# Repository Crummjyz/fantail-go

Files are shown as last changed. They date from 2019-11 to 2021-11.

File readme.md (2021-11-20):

# Fantail Go
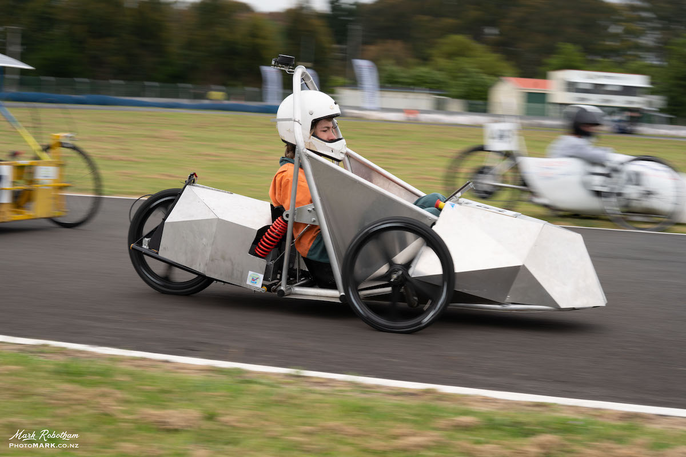
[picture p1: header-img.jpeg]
A go-kart in motion

Throughout 2019, we, a group of students, worked to build an electric go-kart from the ground up. Across the entire vehicle _everything_ was controlled digitally via a pair of Raspberry Pi’s — giving us detailed control over performance, and _lots_ of diagnostics data.

**This repository is not a prepared do-it-yourself project.** Instead, we hope that it might provide some appreciated insight into someone else’s approaches to common problems, for your own work.

The structural and mechanical designs will remain private.

## Repository Structure
#### [vehicle](https://github.com/Crummjyz/fantail-go/tree/main/vehicle)
The code running on each of the onboard Raspberry Pi’s, providing control of the vehicle and data transmission/processing.
_Note — the programs in the ‘tests’ folders are not software tests, but small, isolated scripts to allow manual operation of some hardware components. _

#### [dash](https://github.com/Crummjyz/fantail-go/tree/main/dash)
A Flutter app to display realtime data to the driver.

#### [board](https://github.com/Crummjyz/fantail-go/tree/main/board)
The EAGLE files for our custom PCB/breakout-board.

---- 
_This repository was originally at [https://github.com/Fantail-Dev/fantail-go](https://github.com/Fantail-Dev/fantail-go). It has been migrated here for easier oversight._

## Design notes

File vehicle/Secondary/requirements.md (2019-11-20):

# Requirements (Main Raspberry Pi)
## Tasks
- Send log data to phone for transmission
- Recieve log data from Drive Pi
- Send info data to display
- Read temperatures from sensors
- Read accelerometer data
- Send configuration commands to Drive Pi
- Recieve configuration commands from phone
- Send bluetooth connection setup to tablet or phone
- Read battery voltage
- Read current draw/charge rate

## Connections
| Device | Method
| --- | ---
| Drive Pi | Ethernet
| Phone | USB UART/Bluetooth
| Temperature Sensors/ADC | I<sup>2</sup>C
| Display | USB UART/Bluetooth
| Accelerometer | I<sup>2</sup>C
| Battery Voltage/ADC | I<sup>2</sup>C
| Battery Current/ADC | I<sup>2</sup>C

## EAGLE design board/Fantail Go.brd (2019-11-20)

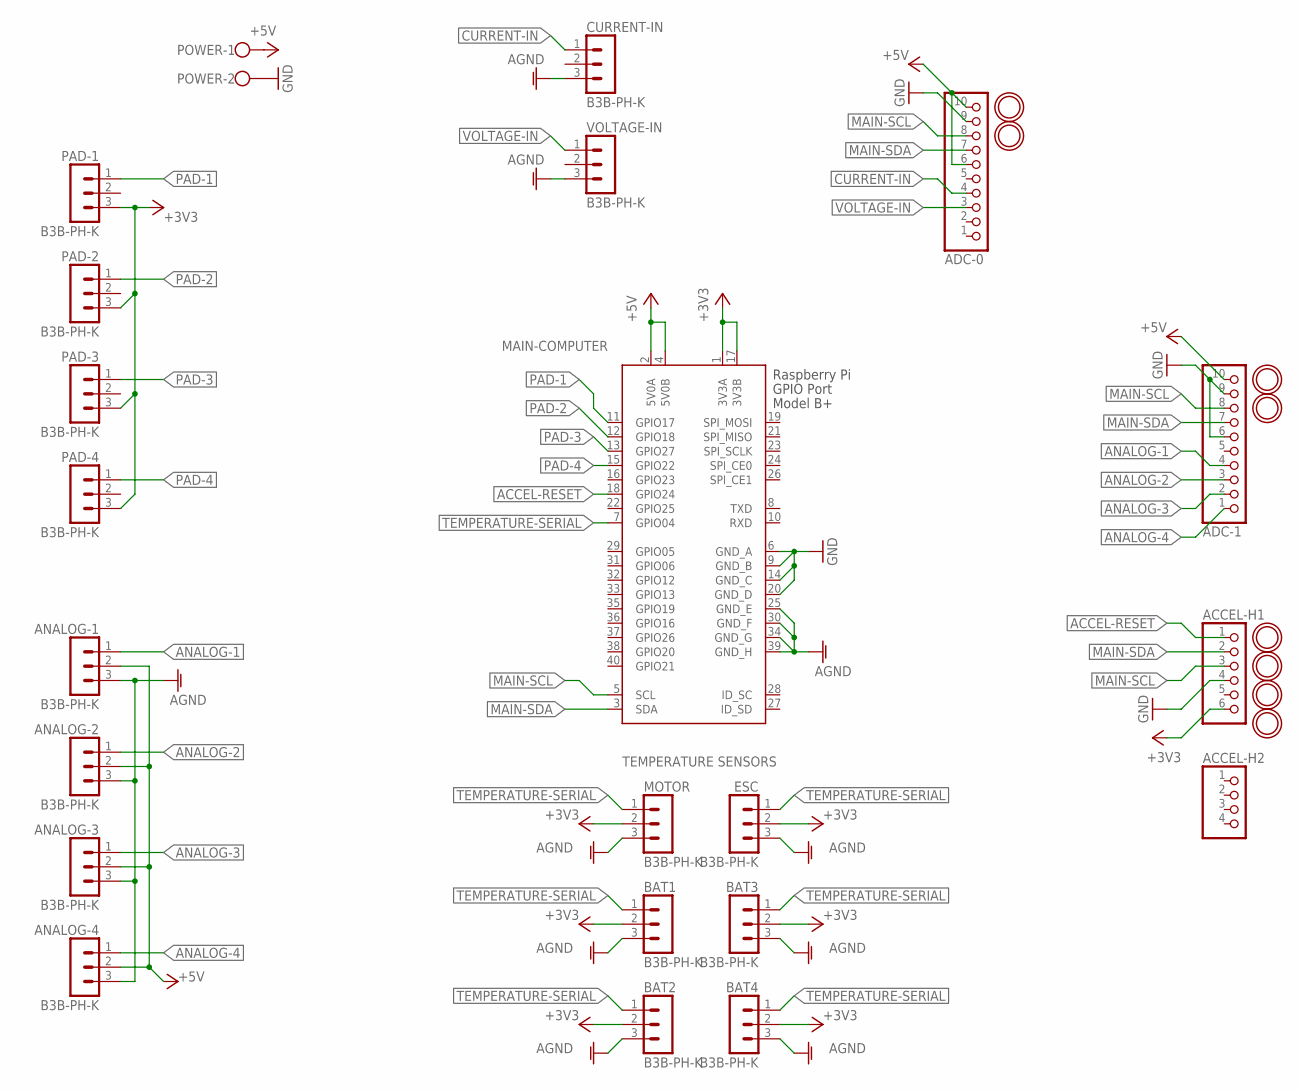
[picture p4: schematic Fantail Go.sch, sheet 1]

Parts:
ACCEL-H1: HEADER-1X670MIL; 1X06_ROUND_70
ACCEL-H2: HEADER-1X4ROUND; 1X04_ROUND
ADC-0, ADC-1: HEADER-1X1070MIL; 1X10_ROUND70
ANALOG-1, ANALOG-2, ANALOG-3, ANALOG-4: B3B-PH-K
BAT1, BAT2, BAT3, BAT4: B3B-PH-K
CURRENT-IN: B3B-PH-K
ESC: B3B-PH-K
MOTOR: B3B-PH-K
PAD-1, PAD-2, PAD-3, PAD-4: B3B-PH-K
POWER: W237-102
U$5, U$15, U$16, U$18, U$19, U$20, U$21, U$22: MOUNTINGHOLE2.5; MOUNTINGHOLE_2.5_PLATED
VOLTAGE-IN: B3B-PH-K
X1: RASPI_BOARD_B+#_F; RASPI_BOARD_B+_FULL

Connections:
+3V3: ACCEL-H1.6, BAT1.2, BAT2.2, BAT3.2, BAT4.2, ESC.2, MOTOR.2, PAD-1.3, PAD-2.3, PAD-3.3, PAD-4.3, X1.1 (3V3A), X1.17 (3V3B)
+5V: ADC-0.6, ADC-0.10, ADC-1.10, ANALOG-1.2, ANALOG-2.2, ANALOG-3.2, ANALOG-4.2, POWER.1, X1.2 (5V0A), X1.4 (5V0B); also elsewhere on the board
ACCEL-RESET: ACCEL-H1.1, X1.18 (GPIO24)
AGND: ANALOG-1.3, ANALOG-2.3, ANALOG-3.3, ANALOG-4.3, BAT1.3, BAT2.3, BAT3.3, BAT4.3, CURRENT-IN.3, ESC.3, MOTOR.3, VOLTAGE-IN.3, X1.25 (GND_E), X1.30 (GND_F), X1.34 (GND_G), X1.39 (GND_H)
ANALOG-1: ADC-1.4, ANALOG-1.1
ANALOG-2: ADC-1.3, ANALOG-2.1
ANALOG-3: ADC-1.2, ANALOG-3.1
ANALOG-4: ADC-1.1, ANALOG-4.1
CURRENT-IN: ADC-0.4, CURRENT-IN.1
GND: ACCEL-H1.4, ADC-0.9, ADC-1.6, ADC-1.9, POWER.2, X1.6 (GND_A), X1.9 (GND_B), X1.14 (GND_C), X1.20 (GND_D); also elsewhere on the board
MAIN-SCL: ACCEL-H1.3, ADC-0.8, ADC-1.8, X1.5 (SCL)
MAIN-SDA: ACCEL-H1.2, ADC-0.7, ADC-1.7, X1.3 (SDA)
PAD-1: PAD-1.1, X1.11 (GPIO17)
PAD-2: PAD-2.1, X1.12 (GPIO18)
PAD-3: PAD-3.1, X1.13 (GPIO27)
PAD-4: PAD-4.1, X1.15 (GPIO22)
TEMPERATURE-SERIAL: BAT1.1, BAT2.1, BAT3.1, BAT4.1, ESC.1, MOTOR.1, X1.7 (GPIO04)
VOLTAGE-IN: ADC-0.3, VOLTAGE-IN.1

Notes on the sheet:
TEMPERATURE SENSORS
MAIN-COMPUTER

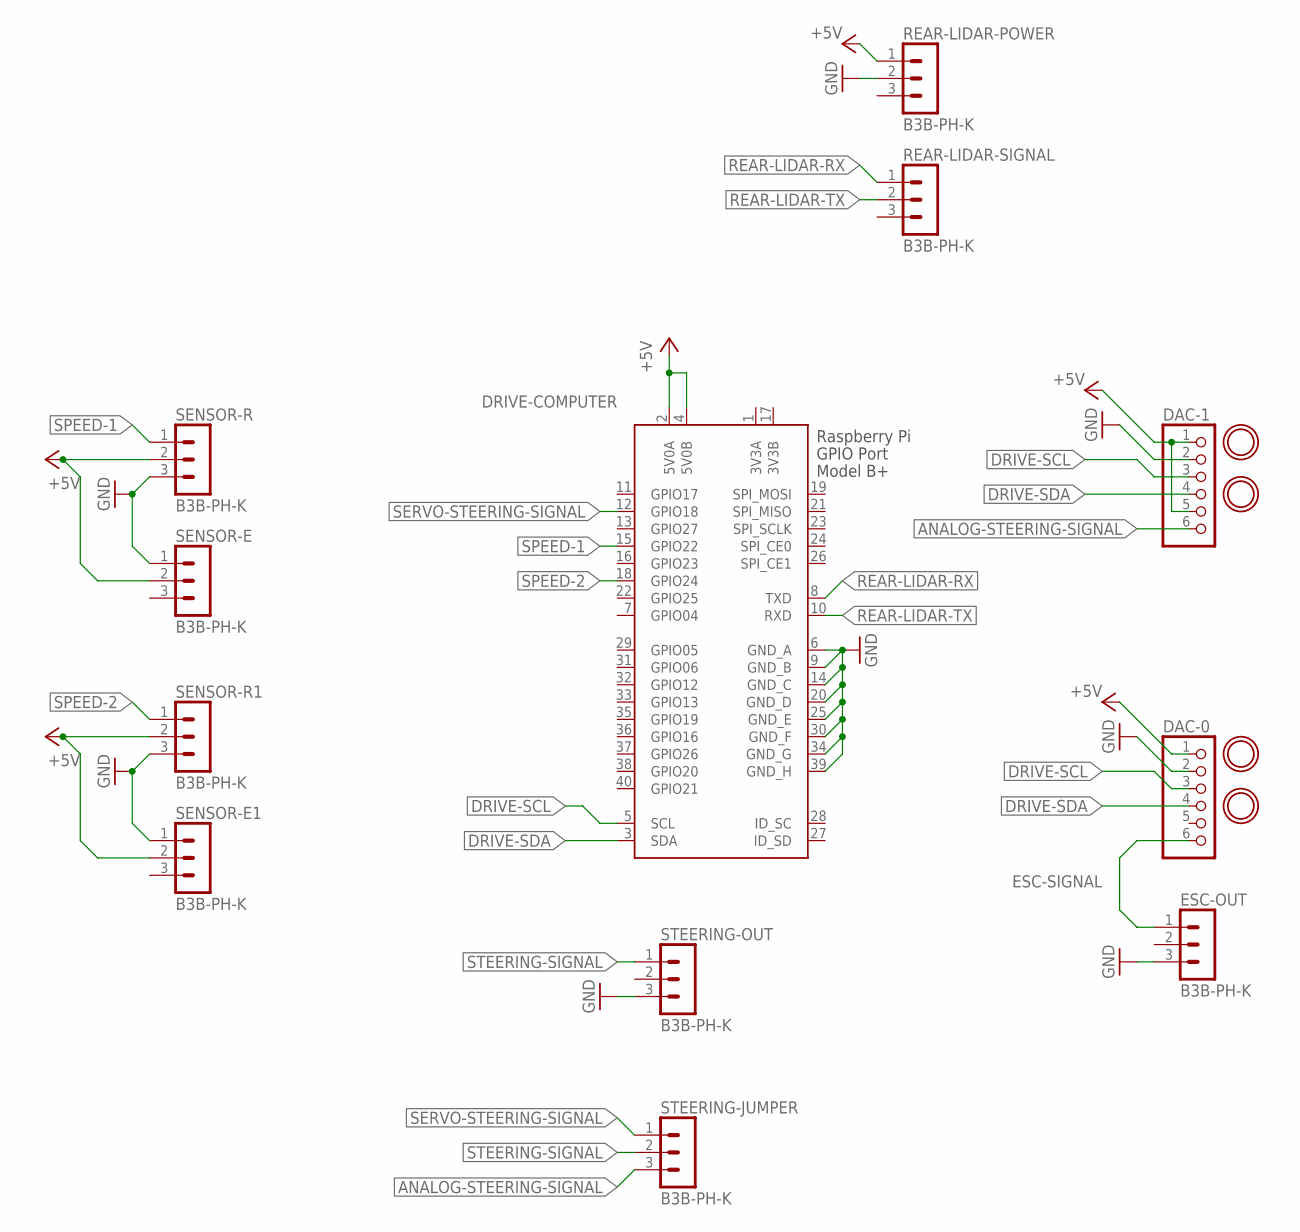
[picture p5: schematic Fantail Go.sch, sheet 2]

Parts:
DAC-0, DAC-1: HEADER-1X670MIL; 1X06_ROUND_70
ESC-OUT: B3B-PH-K
REAR-LIDAR-POWER: B3B-PH-K
REAR-LIDAR-SIGNAL: B3B-PH-K
SENSOR-E, SENSOR-E1: B3B-PH-K
SENSOR-R, SENSOR-R1: B3B-PH-K
STEERING-JUMPER: B3B-PH-K
STEERING-OUT: B3B-PH-K
U$7, U$8, U$11, U$12: MOUNTINGHOLE2.5; MOUNTINGHOLE_2.5_PLATED
X2: RASPI_BOARD_B+#_F; RASPI_BOARD_B+_FULL

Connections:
3V3A: X2.1 (3V3A)
3V3B: X2.17 (3V3B)
+5V: DAC-0.1, DAC-1.1, DAC-1.5, REAR-LIDAR-POWER.1, SENSOR-E.2, SENSOR-E1.2, SENSOR-R.2, SENSOR-R1.2, X2.2 (5V0A), X2.4 (5V0B); also elsewhere on the board
ANALOG-STEERING-SIGNAL: DAC-1.6, STEERING-JUMPER.3
DRIVE-SCL: DAC-0.3, DAC-1.3, X2.5 (SCL)
DRIVE-SDA: DAC-0.4, DAC-1.4, X2.3 (SDA)
ESC-SIGNAL: DAC-0.6, ESC-OUT.1
GND: DAC-0.2, DAC-1.2, ESC-OUT.3, REAR-LIDAR-POWER.2, SENSOR-E.1, SENSOR-E1.1, SENSOR-R.3, SENSOR-R1.3, STEERING-OUT.3, X2.6 (GND_A), X2.9 (GND_B), X2.14 (GND_C), X2.20 (GND_D), X2.25 (GND_E), X2.30 (GND_F), X2.34 (GND_G), X2.39 (GND_H); also elsewhere on the board
REAR-LIDAR-RX: REAR-LIDAR-SIGNAL.1, X2.8 (TXD)
REAR-LIDAR-TX: REAR-LIDAR-SIGNAL.2, X2.10 (RXD)
SERVO-STEERING-SIGNAL: STEERING-JUMPER.1, X2.12 (GPIO18)
SPEED-1: SENSOR-R.1, X2.15 (GPIO22)
SPEED-2: SENSOR-R1.1, X2.18 (GPIO24)
STEERING-SIGNAL: STEERING-JUMPER.2, STEERING-OUT.1

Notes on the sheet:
DRIVE-COMPUTER

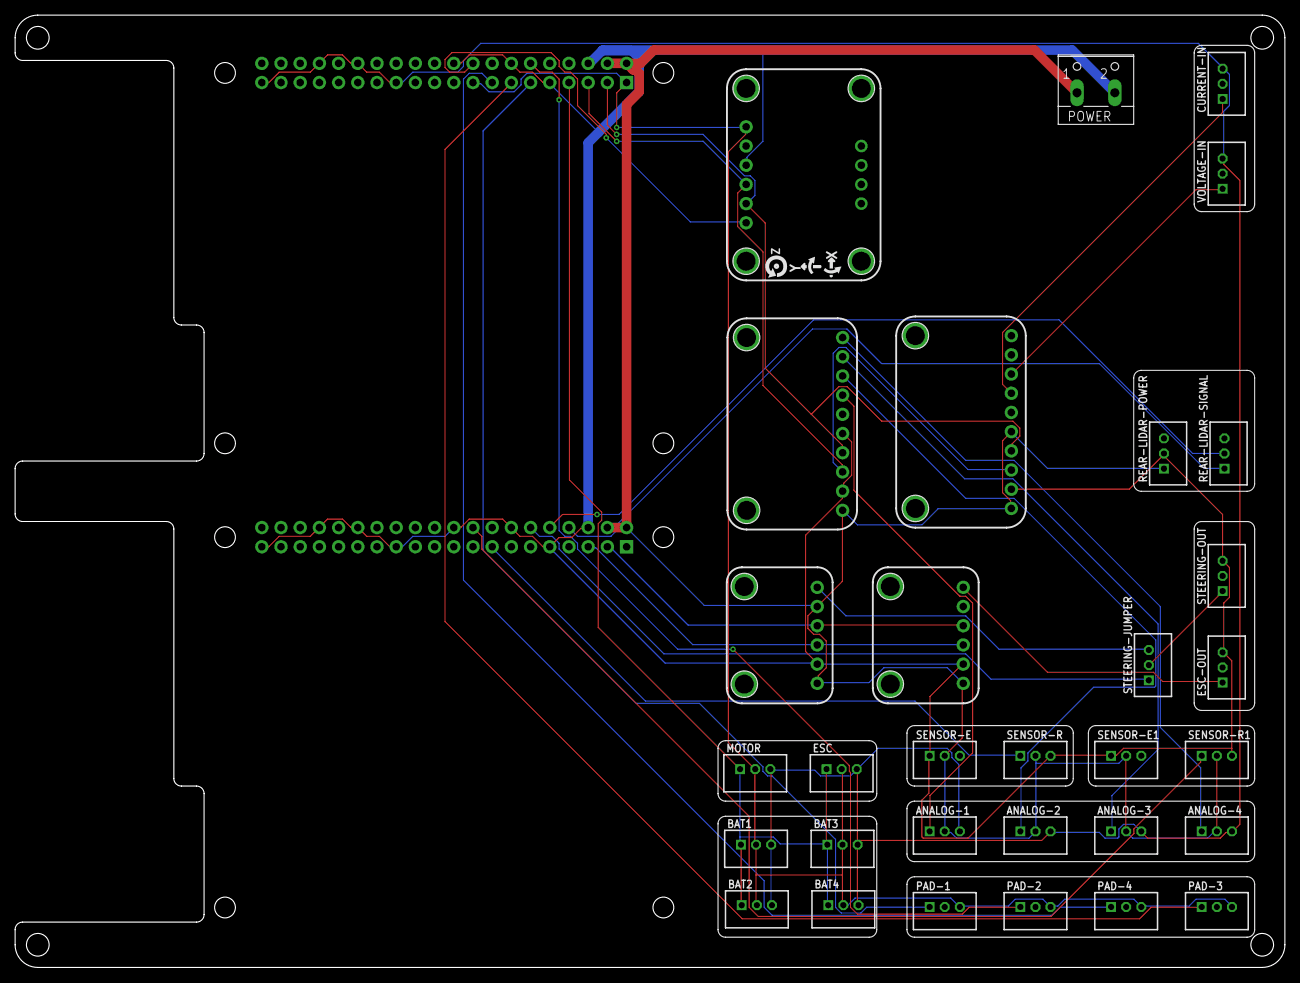
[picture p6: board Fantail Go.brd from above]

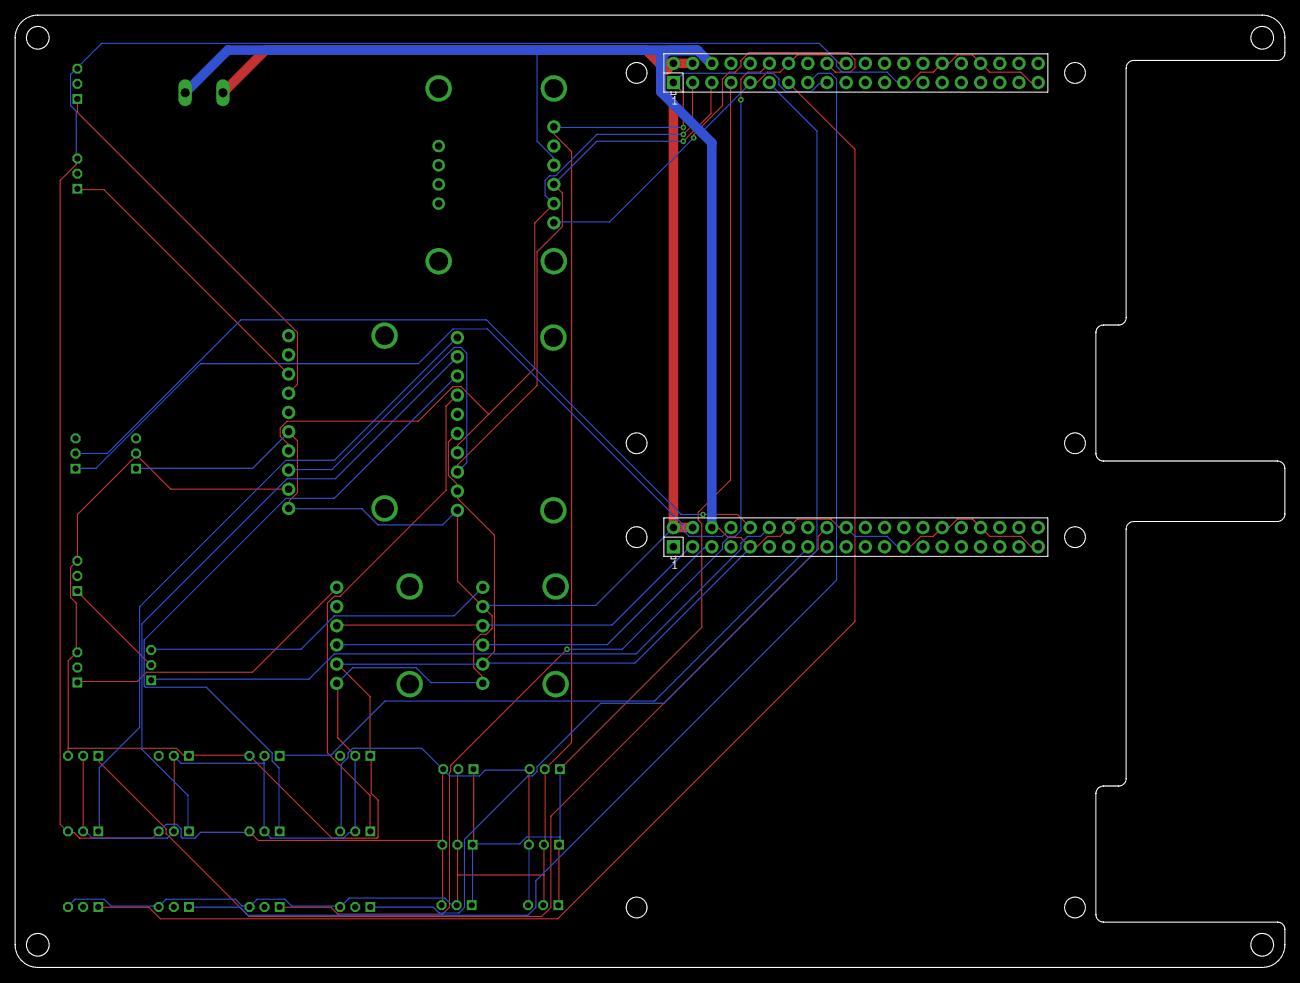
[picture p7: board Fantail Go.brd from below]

Board: 2 copper layers, 168.0 x 126.0 mm, 49 parts (2 on the bottom side), 28 nets.

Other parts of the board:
U$35: SYMBOL_GYRO_CCLOCKWISE
U$36: SYMBOL_GYRO_CLOCKWISE
U$37: SYMBOL_GYRO_Z

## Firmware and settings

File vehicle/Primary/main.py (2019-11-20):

#!/usr/bin/python3

### Setup ###
#region

## Parallelism ##
#region
import multiprocessing
manager = multiprocessing.Manager()
log = manager.dict()
log["exceptions"] = []
#endregion

## Config ##
#region
def setupConfig(config):
  from math import pi
  config['wheelCircumference'] = pi * config['wheelDiameter']
  return config

import json
config = manager.dict()
with open('/home/pi/Vehicle/Primary/config.json') as data:
  loadedData = json.load(data)
  for i in loadedData: # Trust me, there's a reason for this madness.
    config[i] = loadedData[i]
  config = setupConfig(config)
#endregion

## Adafruit Circuitpython ##
#region
import board
import busio
import pulseio
import digitalio
#endregion

#endregion



### Units ###
#region

## Drive Unit ##
#region
# Handles control of the vehicle, primarily through an Xbox controller.
class DriveUnit:

  def setMotor(self, config, log, motor, value):
    value = max(0, min(value, config['maxThrottle']))
    motor.normalized_value = value
    log["driveUnit.motorOutput"] = value

  def setSteering(self, log, steering, value):
    value = max(-1, min(value, 1))
    microseconds = 500 * (value + 3)
    steering.set_servo_pulsewidth(18, microseconds)
    log["driveUnit.steeringOutput"] = value

  def start(self, config, log, local):
    driveUnitProcess = multiprocessing.Process(target = self.main, args = (config, log, local))
    driveUnitProcess.start()

  def main(self, config, log, local):
    from inputs import get_gamepad, UnpluggedError, devices
    from time import sleep

    import adafruit_mcp4725
    i2c = busio.I2C(board.SCL, board.SDA)
    motor = adafruit_mcp4725.MCP4725(i2c)

    # PulseIO is not yet supported on Raspberry Pi
    # (f11384e0 is the last commit with Adafruit Servo code
    # should Pi's be supported in the future.)
    import pigpio
    steering = pigpio.pi()

    reverse = digitalio.DigitalInOut(board.D24)
    reverse.direction = digitalio.Direction.OUTPUT
    reverse.value = True

    boost = False

    currentSteeringSensetivity = 0
    log["driveUnit.reverse"] = False

    while True:
      try:
        leftStickCenter = None
        leftStickPosition = None
        while leftStickCenter == None:
          events = get_gamepad()
          for event in events:
            if event.code == "ABS_X":
              leftStickPosition = event.state
            if event.code == "BTN_SELECT":
              if leftStickPosition != None:
                leftStickCenter = leftStickPosition
                gamepad = devices.gamepads[0]


        while True:
          events = get_gamepad()
          log['driveUnit.controllerConnected'] = True
          for event in events:
            if event.code == "BTN_SELECT":
              leftStickCenter = leftStickPosition

            if event.code == "BTN_WEST":
              reverse.value = not event.state
              log["driveUnit.reverse"] = not reverse.value # The reverse pin/transistor is pulled the wrong way, so this double invert is needed.
            
            if event.code == "BTN_EAST":
              boost = event.state
              log["driveUnit.boost"] = boost

            if event.code == "ABS_X":
              leftStickPosition = event.state
              steeringInput = event.state - leftStickCenter
              log["driveUnit.steeringInput"] = steeringInput
              steeringNormalized = steeringInput / 16384
              speed = speedUnit.getSpeed(config, speedUnitLocal)
              if speed > 10 and config['speedSteeringSensitivity']: # Ajust steering sensetivity/range based on speed.
                if speed < currentSteeringSensetivity:
                  if -config['steeringDeadzone'] < steeringNormalized < config['steeringDeadzone']:
                    steeringNormalized = steeringNormalized / (speed / 10) # Adjust steering sensitivity based on speed.
                    currentSteeringSensetivity = speed
                else:
                  steeringNormalized = steeringNormalized / (speed / 10) # Adjust steering sensitivity based on speed.
                  currentSteeringSensetivity = speed
              steeringNormalized = steeringNormalized * config['steeringSensitivity']
              
              if -config['steeringDeadzone'] < steeringNormalized < config['steeringDeadzone']:
                steeringNormalized = 0
              elif steeringNormalized < 0:
                steeringNormalized += config['steeringDeadzone']
              elif steeringNormalized > 0:
                steeringNormalized -= config['steeringDeadzone']

              self.setSteering(log, steering, steeringNormalized)

            elif event.code == "ABS_RZ":
              throttleInput = event.state
              log["driveUnit.throttleInput"] = throttleInput
              throttleNormalized = ((throttleInput * (0.76 - 0.18)) / 1024) + 0.18 # Motor activates at ~0.24
              if throttleNormalized > 0.2 and boost:
                throttleNormalized = 1
              self.setMotor(config, log, motor, throttleNormalized)
      except Exception as exception:
        log["exceptions"].append(str(exception))
        if type(exception) == UnpluggedError:
          log['driveUnit.controllerConnected'] = False
        motor.normalized_value = 0
        reverse.value = 0

#endregion

## Speed Unit ##
#region
# Measures the speed of the vehicle.
class SpeedUnit:

  def start(self, config, log, local):
    speedUnitProcess = multiprocessing.Process(target = self.main, args = (config, log, local))
    speedUnitProcess.start()

  def main(self, config, log, local):
    from time import time

    breakBeam = digitalio.DigitalInOut(board.D22)
    breakBeam.direction = digitalio.Direction.INPUT
    breakBeam.pull = digitalio.Pull.UP

    local.ticks = 0
    local.recentTicks = []

    while True:
      try:
        while True:
          end = time() + config['speedMeasurementDuration']
          currentBeamState = 0
          ticks = 0

          while time() < end:
            if breakBeam.value != currentBeamState:
              currentBeamState = breakBeam.value
              if currentBeamState == 1:
                ticks += 1

          local.ticks = ticks

          recentTicks = local.recentTicks
          if len(recentTicks) >= config['speedAveragingHistory']:
            del recentTicks[-1]
          recentTicks.insert(0, ticks)
          local.recentTicks = recentTicks

      except Exception as exception:
        log["exceptions"].append(str(exception))

  def getSpeed(self, config, local, SI=False): # SI will return in metres/second.
    if len(local.recentTicks) < 1:
      return 0
    recentTicks = local.recentTicks.copy()
    for i, x in enumerate(recentTicks):
      recentTicks[i] = x * (1 / len(recentTicks)) * (len(recentTicks) - i)
    averageTicks = sum(recentTicks)/len(recentTicks)
    rotations = averageTicks / 5
    distance = rotations * config['wheelCircumference']
    mmS = distance * (1 / config['speedMeasurementDuration'])
    if mmS < 315:
      return 0
    if SI:
      return mmS * 0.001

    return mmS * 0.0036

#endregion

## Lidar Unit
#region
# Scans the environment with the Lidar.
class LidarUnit:

  def start(self, config, log, local):
    lidarUnitProcess = multiprocessing.Process(target = self.main, args = (config, log, local))
    lidarUnitProcess.start()

  def main(self, config, log, local):
    from adafruit_rplidar import RPLidar

    from math import cos, sin, radians

    while True:
      try:
        lidar = RPLidar(None, config['lidarPort'])
        lidar.set_pwm(config['lidarSpeed'])

        try: # Rear LIDAR failure will not impact main LIDAR
          import adafruit_tfmini
          import serial
          uart = serial.Serial("/dev/ttyS0", timeout=1)
          rearLidar = adafruit_tfmini.TFmini(uart)
          rearLidar.mode = adafruit_tfmini.MODE_SHORT
        except Exception as exception:
          log["exceptions"].append(str(exception))
        while True:
          for scan in lidar.iter_scans():
            local.scan = scan
            try:
              rearScan = (rearLidar.distance - config['rearLidarOverhang'], rearLidar.strength, rearLidar.mode)
              if rearScan[0] <= 0:
                rearScan = (None, rearScan.strength, rearScan.mode)
              local.rearScan = rearScan
            except Exception as exception:
              log["exceptions"].append(str(exception))
      except Exception as exception:
        log["exceptions"].append(str(exception))
        if type(exception) == KeyboardInterrupt: # This might not work because it runs it a separate process.
          lidar.stop()
          lidar.disconnect()

  def getLidar(self, config, local, flattened=False):
    if flattened:
      flattenedScan = []
      for (quality, angle, distance) in local.scan:
        flattenedDistance = distance * cos(radians(config['lidarAngle'] * cos(radians(angle))))
        flattenedScan.append((quality, angle, flattenedDistance))
      return flattenedScan

    return local.scan
  
  def getRearLidar(self, config, local):
    return lidarUnitLocal.rearScan

#endregion

## Log Unit ##
#region
# Records and transmits extensive log data back to the Fantail Go database/server.
class LogUnit:

  def start(self, config, log):
    logUnitProcess = multiprocessing.Process(target = self.main, args = (config, log))
    logUnitProcess.start()

  def main(self, config, log):
    import socket
    from datetime import datetime

    while True:
      try:
        while True:
          # Add config to log here.
          logOutput = {}
          logOutput["@timestamp"] = datetime.now().strftime("%Y-%m-%dT%H:%M:%S.%f")[:-3]
          logOutput["@metadata"] = {
            "beat":"fantail-primary"
          }

          logOutput["config"] = config.copy()
          logOutput.update(log.copy()) # Add all the current inline log values to the output.
          try:
            logOutput["speedUnit.speed"] = speedUnit.getSpeed(config, speedUnitLocal)
          except Exception:
            pass
          try:
            logOutput["lidarUnit.scan"] = lidarUnit.getLidar(config, lidarUnitLocal)
            logOutput["lidarUnit.rearScan"] = lidarUnit.getRearLidar(config, lidarUnitLocal)
          except Exception:
            pass
          try:
            logOutput["lidarUnit.rearScan"] = lidarUnit.getRearLidar(config, lidarUnitLocal)
          except Exception:
            pass

          tcpSocket = socket.socket(socket.AF_INET, socket.SOCK_STREAM)
          serverAddress = (config["logServer"], config["logPort"])
          tcpSocket.connect(serverAddress)
          message = json.dumps(logOutput) + "\n"
          tcpSocket.sendall(bytes(message, 'UTF-8'))
          tcpSocket.close()
      except Exception as exception:
        # Well... crap
        print(exception)

#endregion

## Data Unit ##
#region
# Manages data transfers between the onboard computers.
class DataUnit:

  def start(self, config, log, local, dataQueue):
    dataUnitProcess = multiprocessing.Process(target = self.main, args = (config, log, local, dataQueue))
    dataUnitProcess.start()

  def main(self, config, log, local, dataQueue):
    while True:
      try:
        asyncio.get_event_loop().run_until_complete(self.server(config, dataQueue))

      except Exception as exception:
        log["exceptions"].append(str(exception))

  async def server(self, config, dataQueue):
    import websockets
    async with websockets.connect("ws://{}:{}".format(config['secondaryComputerAddress'], config['dataPort'])) as websocket:
      while True:
        if len(dataQueue) > 0:
          await websocket.send(json.dumps(dataQueue.copy()))
          dataQueue.clear()
        #receivedData = await websocket.recv()
        # As there is currently no data send to this Pi, don't bother receiving any.

  def sendData(self, prefix, data, dataQueue):
    dataQueue[prefix] = json.dumps(data)

#endregion

## Dashboard Unit ##
#region
# Packages data to be sent to the dashboard.
class DashboardUnit:

  def start(self, config, log, local, dataQueue):
    dashboardUnitProcess = multiprocessing.Process(target = self.main, args = (config, log, local, dataQueue))
    dashboardUnitProcess.start()

  def main(self, config, log, local, dataQueue):
    while True:
      try:
        while True:
          data = {}
          data['infoItems'] = []

          try:
            data['speed'] = speedUnit.getSpeed(config, speedUnitLocal)
          except Exception:
            pass

          try:
            data['controller'] = log['driveUnit.controllerConnected']
          except Exception:
            pass

          try:
            if log['driveUnit.reverse']:
              data['mode'] = 2
            else:
              data['mode'] = 1
          except Exception:
            pass

          try:
            data['lidarScan'] = lidarUnit.getLidar(config, lidarUnitLocal, flattened=True)
          except Exception:
            pass
          
          try:
            data["rearLidarScan"] = lidarUnit.getRearLidar(config, lidarUnitLocal)
            if log['driveUnit.reverse']:
              data['infoItems'].append({
                "icon": "info",
                "title": "{}cm Reversing Space".format(data["rearLidarScan"])
              })
          except Exception:
            pass

          dataUnit.sendData("dash", data, dataQueue)

      except Exception as exception:
        log["exceptions"].append(str(exception))

#endregion

#endregion

### Control Code ###
#region

## Speed Unit ##
#region
speedUnitLocal = manager.Namespace()
speedUnit = SpeedUnit()
speedUnit.start(config, log, speedUnitLocal)
#endregion

## Drive Unit ##
#region
driveUnitLocal = manager.Namespace()
driveUnit = DriveUnit()
driveUnit.start(config, log, driveUnitLocal)
#endregion

## Lidar Unit ##
#region
lidarUnitLocal = manager.Namespace()
lidarUnit = LidarUnit()
lidarUnit.start(config, log, lidarUnitLocal)
#endregion

## Log Unit ##
#region
logUnit = LogUnit()
logUnit.start(config, log)
#endregion

## Data Unit ##
#region
import asyncio
dataUnitLocal = manager.Namespace()
dataUnitQueue = manager.dict()
dataUnit = DataUnit()
dataUnit.start(config, log, dataUnitLocal, dataUnitQueue)
#endregion

## Dashboard Unit ##
#region
dashboardUnitLocal = manager.Namespace()
dashboardUnit = DashboardUnit()
dashboardUnit.start(config, log, dashboardUnitLocal, dataUnitQueue)
#endregion

# Keep the main thread alive.
while True:
  pass

#endregion

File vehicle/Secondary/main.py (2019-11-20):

#!/usr/bin/python3

### Setup ###
#region

## Parallelism ##
#region
import multiprocessing
manager = multiprocessing.Manager()
log = manager.dict()
log['exceptions'] = []
#endregion

## Config ##
#region
def setupConfig(config):
  # Set up other config values here.
  return config

import json
config = manager.dict()
with open('/home/pi/Vehicle/Secondary/config.json') as data:
  loadedData = json.load(data)
  for i in loadedData: # Trust me, there's a reason for this madness.
    config[i] = loadedData[i]
  config = setupConfig(config)
#endregion

## Adafruit Circuitpython ##
#region
import board
import busio
#endregion

#endregion



### Units ###
#region

## Temperature Unit ##
#region
class TemperatureUnit:

  def readRawData(self, sensor):
    f = open(sensor, 'r')
    lines = f.readlines()
    f.close()
    return lines

  def start(self, log, local):
    temperatureUnitProcess = multiprocessing.Process(target = self.main, args = (log, local))
    temperatureUnitProcess.start()

  def main(self, log, local):
    import glob
    from time import sleep

    directories = glob.glob("/sys/bus/w1/devices/28*")
    temperatureSensors = []
    local.temperatures = []
    for directory in directories:
      temperatureSensors.append(directory + "/w1_slave")

    while True:
      try:
        while True:
          temperatures = []
          for sensor in temperatureSensors:
            lines = self.readRawData(sensor)
            while lines[0].strip()[-3:] != 'YES':
              sleep(0.2)
              lines = self.readRawData(sensor)
            equalsPosition = lines[1].find('t=')
            if equalsPosition != -1:
              temperatureString = lines[1][equalsPosition+2:]
              temperature = float(temperatureString) / 1000
              temperatures.append(temperature)
          local.temperatures = temperatures
      except Exception as exception:
        log["exceptions"].append(str(exception))

  def getTemperature(self, config, local, sensor="ALL"):
    if sensor == "ALL":
      temperatures = {
        "motor": local.temperatures[config["temperatureSensors"]["motor"]],
        "speedController": local.temperatures[config["temperatureSensors"]["speedController"]],
        "battery1": local.temperatures[config["temperatureSensors"]["battery1"]],
        "battery2": local.temperatures[config["temperatureSensors"]["battery2"]],
        "battery3": local.temperatures[config["temperatureSensors"]["battery3"]],
        "battery4": local.temperatures[config["temperatureSensors"]["battery4"]]
      }
      return temperatures

    return local.temperatures[config["temperatureSensors"][sensor]]

#endregion

## Log Unit ##
#region
# Records and transmits extensive log data back to the Fantail Go database/server.
class LogUnit:

  def start(self, config, log):
    logUnitProcess = multiprocessing.Process(target = self.main, args = (config, log))
    logUnitProcess.start()

  def main(self, config, log):
    import socket
    from datetime import datetime

    while True:
      try:
        while True:
          # Add config to log here.
          logOutput = {}
          logOutput["@timestamp"] = datetime.now().strftime("%Y-%m-%dT%H:%M:%S.%f")[:-3]
          logOutput["@metadata"] = {
            "beat":"fantail-secondary"
          }

          logOutput["config"] = config.copy()
          logOutput.update(log.copy()) # Add all the current inline log values to the output.
          try:
            logOutput["temperatureUnit.temperatures"] = temperatureUnit.getTemperature(config, temperatureUnitLocal)
          except Exception:
            pass

          tcpSocket = socket.socket(socket.AF_INET, socket.SOCK_STREAM)
          serverAddress = (config["logServer"], config["logPort"])
          tcpSocket.connect(serverAddress)
          message = json.dumps(logOutput) + "\n"
          tcpSocket.sendall(bytes(message, 'UTF-8'))
          tcpSocket.close()
      except Exception as exception:
        # Well... crap
        print(exception)

#endregion

## Data Unit ##
#region
# Manages data transfers between the onboard computers.
class DataUnit:

  def start(self, config, log, local, dataQueue):
    dataUnitProcess = multiprocessing.Process(target = self.main, args = (config, log, local, dataQueue))
    dataUnitProcess.start()

  def main(self, config, log, local, dataQueue):
    import websockets

    while True:
      try:
        asyncio.get_event_loop().run_until_complete(websockets.serve(self.server, config['hostAddress'], config['dataPort']))
        asyncio.get_event_loop().run_forever()

      except Exception as exception:
        log["exceptions"].append(str(exception))

  async def server(self, websocket, path):
    while True:
      receivedData = await websocket.recv()
      receivedData = json.loads(receivedData)
      dataUnitLocal.dash = receivedData['dash']

#endregion

## Dashboard Unit ##
#region
# Packages data to be sent to the dashboard.
class DashboardUnit:

  def start(self, config, log, local):
    dashboardUnitProcess = multiprocessing.Process(target = self.main, args = (config, log, local))
    dashboardUnitProcess.start()

  def main(self, config, log, local):
    import websockets

    while True:
      try:
        asyncio.get_event_loop().run_until_complete(websockets.serve(self.server, config['hostAddress'], config['dashCommunicationPort']))
        asyncio.get_event_loop().run_forever()

      except Exception as exception:
        log["exceptions"].append(str(exception))

  async def server(self, websocket, path):
    while True:
      packet = json.loads(dataUnitLocal.dash)
      packet['infoItems'] = []
      try:
        packet['primaryBattery'] = log['batteryUnit.batteryVoltage'] / 5
      except Exception:
        pass
      try:
        packet['secondaryBattery'] = log['batteryUnit.subBatteryVoltage'] / 5
      except Exception:
        pass
      packet = json.dumps(packet)
      await websocket.send(packet)

#endregion

## Battery Unit ##
#region
# Monitors the status of the batteries and high voltage equipment.
class BatteryUnit:

  def start(self, log, local):
    batteryUnitProcess = multiprocessing.Process(target = self.main, args = (log, local))
    batteryUnitProcess.start()

  def main(self, log, local):
    import adafruit_ads1x15.ads1015 as adafruit_ads1015
    from adafruit_ads1x15.analog_in import AnalogIn
    i2c = busio.I2C(board.SCL, board.SDA)
    batteryMonitor = adafruit_ads1015.ADS1015(i2c, address=0x49)

    batteryVoltage = AnalogIn(batteryMonitor, adafruit_ads1015.P0)
    subBatteryVoltage = AnalogIn(batteryMonitor, adafruit_ads1015.P1)

    while True:
      try:
        while True:
          log['batteryUnit.batteryVoltage'] = batteryVoltage.voltage
          log['batteryUnit.subBatteryVoltage'] = subBatteryVoltage.voltage

      except Exception as exception:
        log["exceptions"].append(str(exception))

#endregion

#endregion



### Control Code ###
#region
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

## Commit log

2019-11-20 Add PCB files
    [Fantail Go.brd, Fantail Go.sch]
2021-11-20 Update README.md ahead of archival
    [Fantail Go.brd, Fantail Go.sch]

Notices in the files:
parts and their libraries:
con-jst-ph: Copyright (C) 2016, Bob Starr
